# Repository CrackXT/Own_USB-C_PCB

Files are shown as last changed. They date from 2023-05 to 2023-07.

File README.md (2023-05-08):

# USB-C_PCB

PCB files for USB Power Mainboard

# Description

This board enables the installation of a USB-C connection with a voltage and current regulator connected behind it.

Like this... https://www.pololu.com/product/4083

Used to operate your microcontroller board with constant voltage and regulated current via a USB-C power supply. - To limit over-voltage and over-current and prevent damage. 

The board can be produced here (AISLER) with the files (.brd and .sch) or by any other PCB manufacturer. -> https://aisler.net/

# Spec
Vin:  2,8 - 22V<br>
Vout: 5V (typ., min.4,85V, max.5,15V)<br>
Iout: 1A

# Serie

- .pro

# Layout

Top<br>
UBS-C_Top_v4 0

Bottom<br>
UBS-C_Bottom_v4 0

Routing/Dimensions(inch)<br>
USB-C_v4 0

Schematic<br>
Schematic as .pdf at the top of the page.

# License

Open hardware, use it, mod it, whatever you want, feel free...

# Thanks!

Own design and layout.

# Version - Build

v4.0 - 07.05.2023

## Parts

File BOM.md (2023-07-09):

# BOM - List

part list for Use

# USB-C
1x USB-C connector https://www.digikey.de/de/products/detail/gct/USB4125-GF-A-0190/14559038

# regulator
1x S13V10F5 https://eckstein-shop.de/Pololu-5V-1A-Step-Up-Step-Down-Voltage-Regulator-S13V10F5

# connector
1x JST-PH2 (THT - Axial) https://www.reichelt.de/jst-stiftleiste-gerade-1x2-polig-ph-jst-ph2p-st-p185049.html?&trstct=pos_11&nbc=1

# led
1x white 0805 https://www.digikey.de/de/products/detail/everlight-electronics-co-ltd/EAST2012WA1/11200795

# resistor
1x 2200Ohm 0805 https://www.reichelt.de/smd-widerstand-0805-2-2-kohm-125-mw-0-1--spr-0805-2-20k-p123266.html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<br>
2x 5100Ohm 0805 https://www.reichelt.de/smd-widerstand-0805-5-1-kohm-125-mw-0-1--spr-0805-5-10k-p123287.html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<br>

# capacitor
1x 47µF 2220 https://www.digikey.de/de/products/detail/tdk-corporation/C5750X7R1V476M230KC/15930210

# socket strips
1x 1X3 https://www.reichelt.de/buchsenleiste-2-54mm-1x3-gerade-bkl-10120945-p266670.html?&trstct=pol_1&nbc=1

# pin headers
1x 1X36 (1X3) https://www.conrad.de/de/p/fischer-elektronik-stiftleiste-standard-anzahl-reihen-1-polzahl-je-reihe-36-sl-lp-1-082-36-z-1-st-739416.html

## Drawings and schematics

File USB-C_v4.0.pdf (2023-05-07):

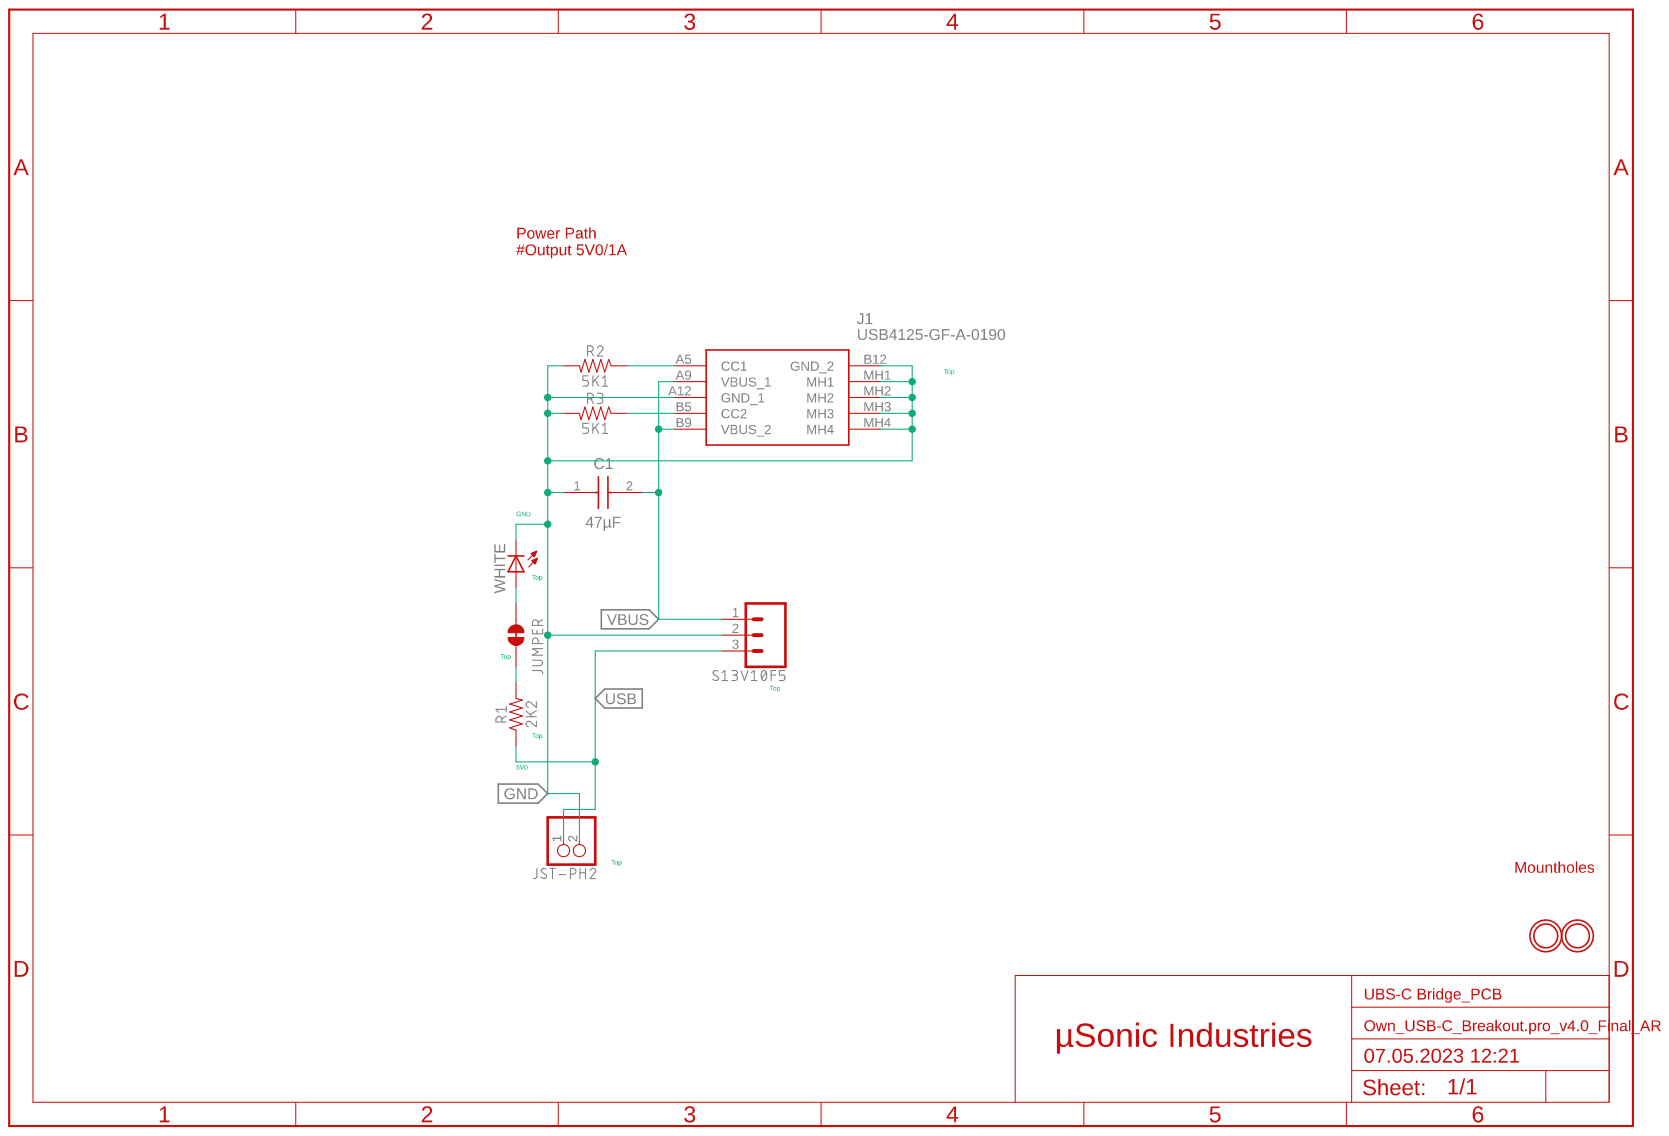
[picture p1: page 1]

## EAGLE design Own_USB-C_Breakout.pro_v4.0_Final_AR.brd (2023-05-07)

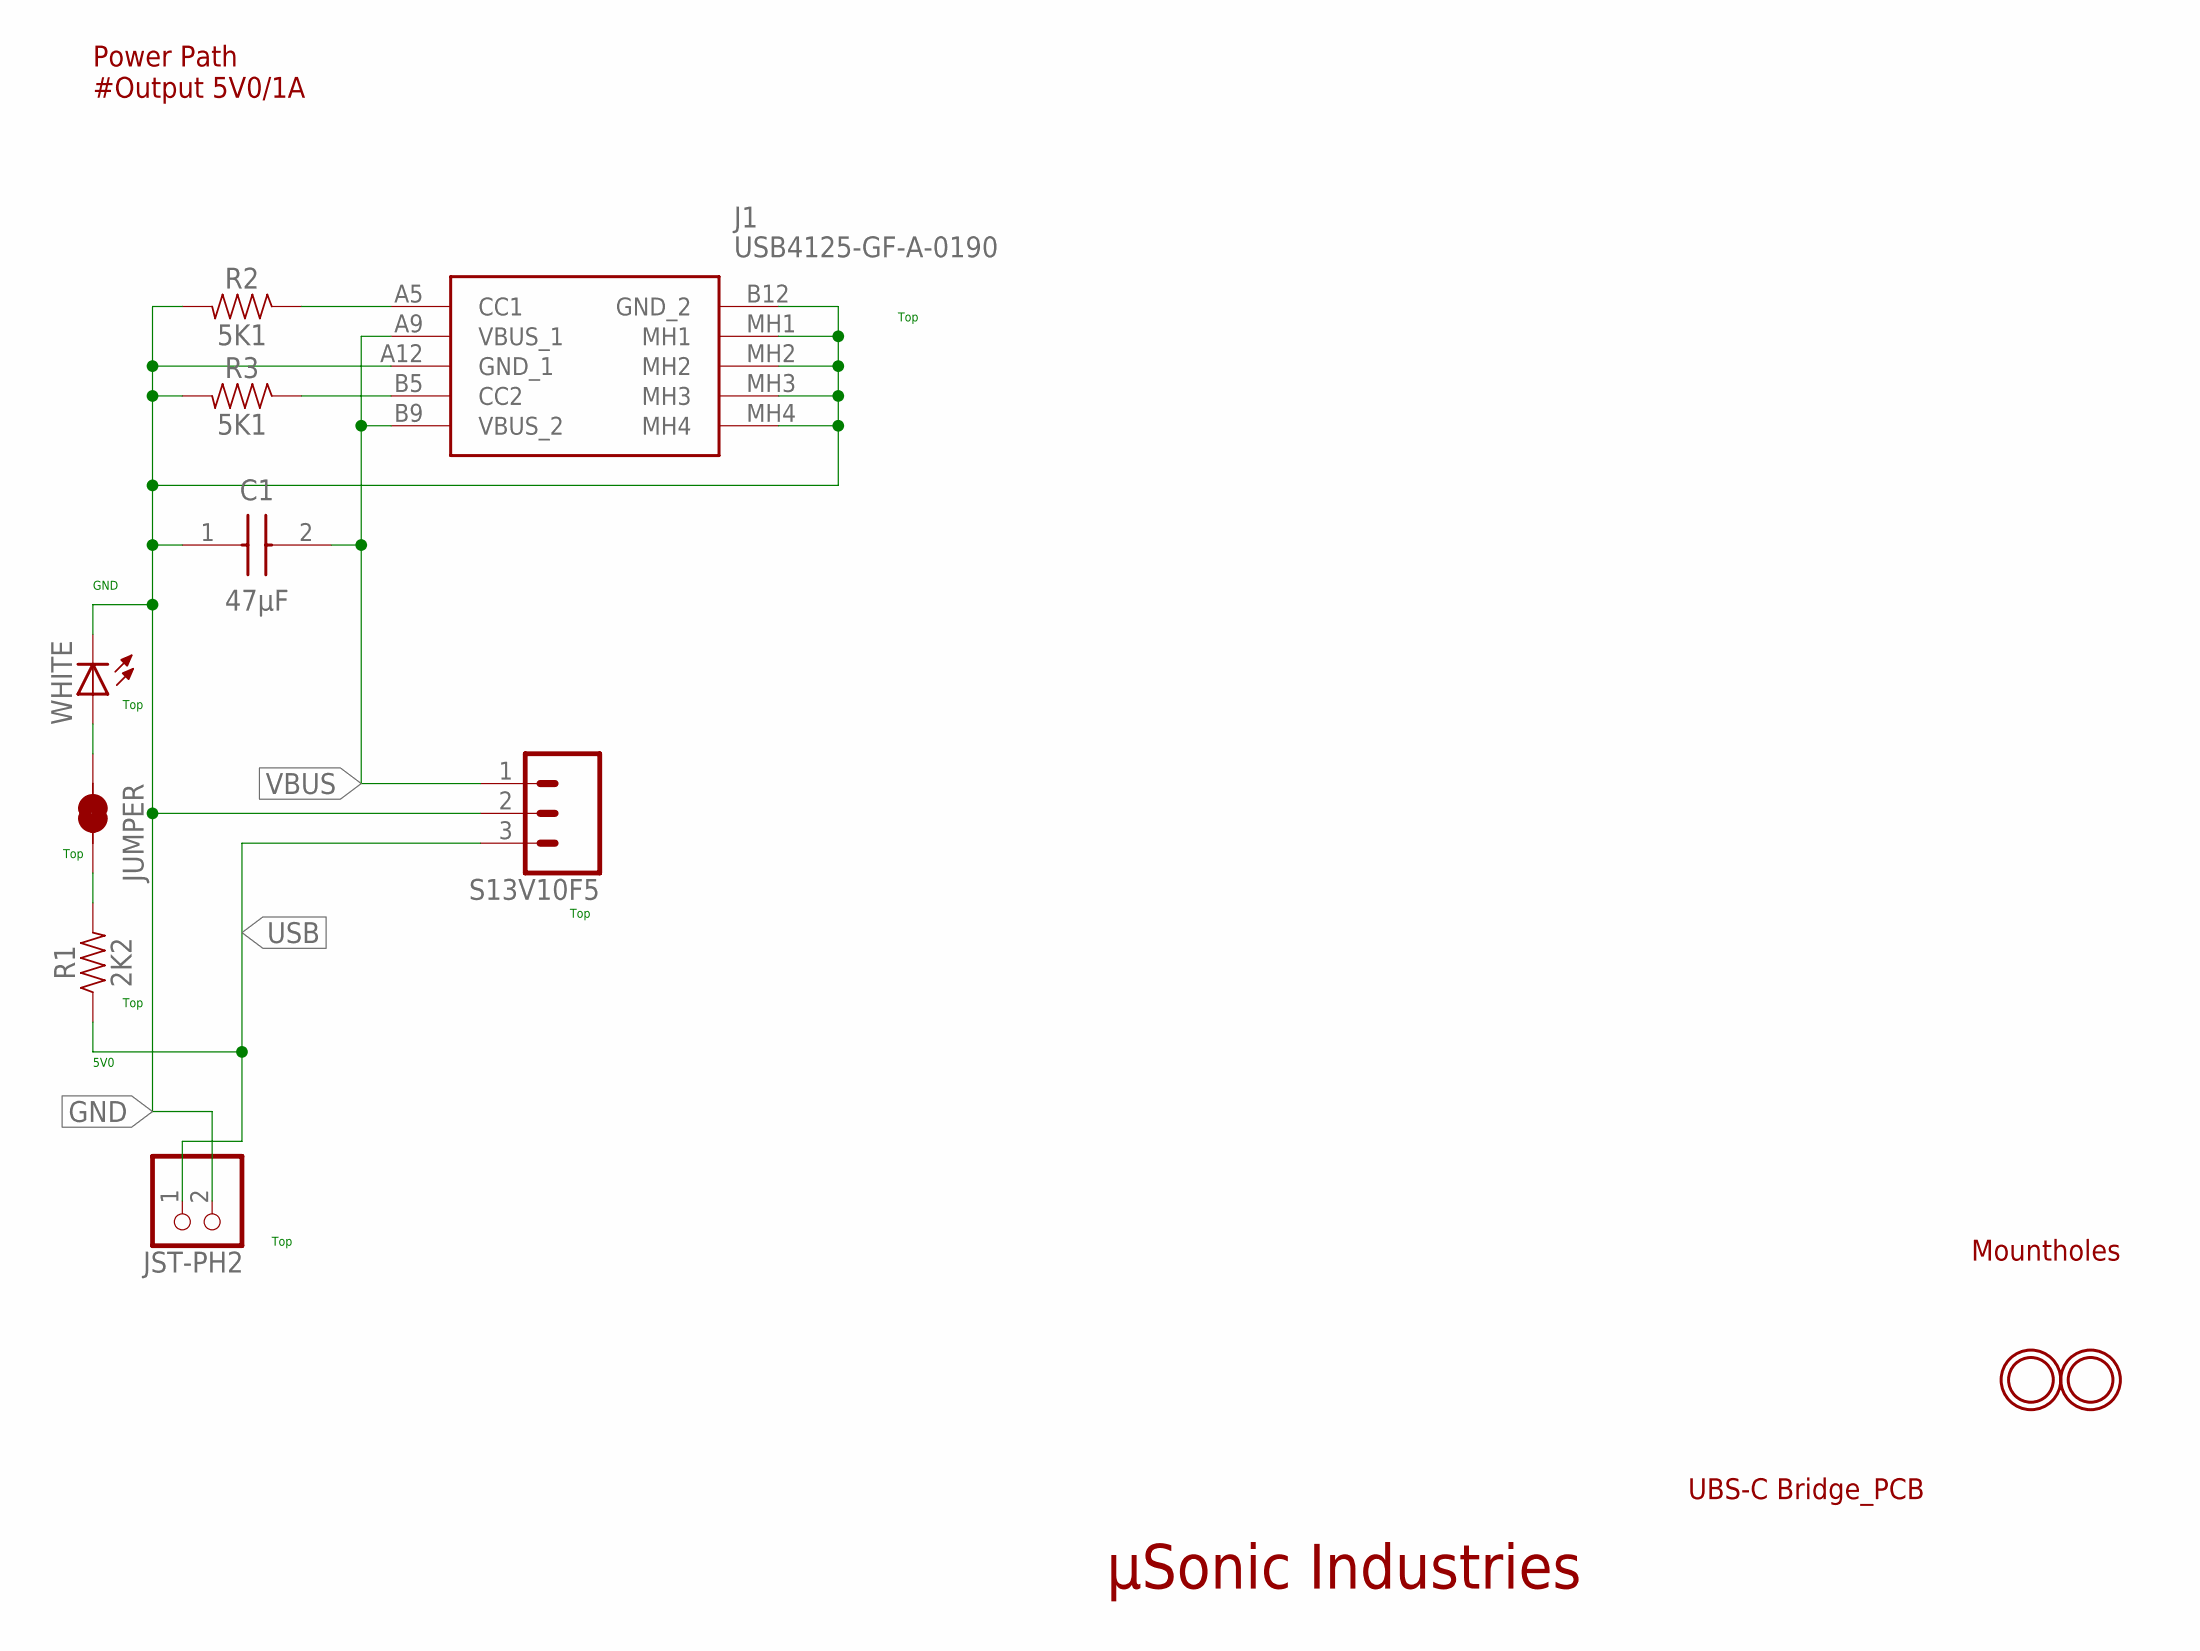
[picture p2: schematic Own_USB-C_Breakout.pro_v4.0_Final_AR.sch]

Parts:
C1: 47µF; CAPC5750X310N
J1: USB4125-GF-A-0190; USB4125GFA0190
JST-PH2: JST_2PINOWN; JST-PH-2-THMOWN
JUMPER: JUMPER-SMT_2_NC_TRACE_SILK; SMT-JUMPER_2_NC_TRACE_SILK
R1: 2K2; 0805
R2, R3: 5K1; 0805
S13V10F5: CONN_031X03_NO_SILK; 1X03_NO_SILK
U$1, U$2: MOUNTINGHOLE2.5; MOUNTINGHOLE_2.5_PLATED
WHITE: LEDCHIPLED_0805; CHIPLED_0805

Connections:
GND: C1.1, J1.A12 (GND_1), J1.B12 (GND_2), J1.MH1, J1.MH2, J1.MH3, J1.MH4, JST-PH2.2 (1), R2.2, R3.2, S13V10F5.2, WHITE.C
JUMPER1: JUMPER.1, WHITE.A
JUMPER2: JUMPER.2, R1.2
unnamed: J1.B5 (CC2), R3.1
unnamed: J1.A5 (CC1), R2.1
USB: JST-PH2.1 (2), R1.1, S13V10F5.3
VBUS: C1.2, J1.A9 (VBUS_1), J1.B9 (VBUS_2), S13V10F5.1

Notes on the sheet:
µSonic Industries
UBS-C Bridge_PCB
Power Path #Output 5V0/1A
Top
Mountholes
GND
5V0

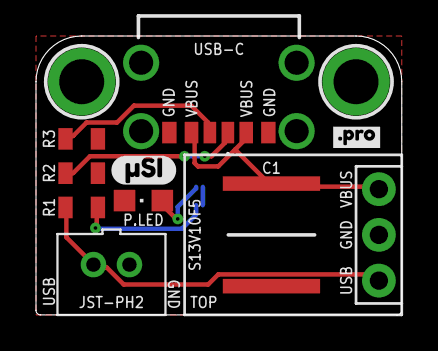
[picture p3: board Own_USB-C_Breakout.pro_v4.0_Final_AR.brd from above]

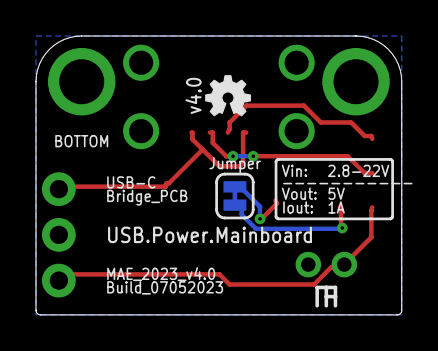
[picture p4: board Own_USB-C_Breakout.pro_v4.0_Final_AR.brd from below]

Board: 2 copper layers, 20.3 x 15.5 mm, 14 parts (2 on the bottom side), 7 nets.

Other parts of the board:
U$4: PRO2
U$6: OSHW-LOGO-MINI
U$7: µSI2

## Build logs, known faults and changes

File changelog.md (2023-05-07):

# Version - Build
v1.0 - 09.10.2021
- First Release

v2.0 - 20.01.2022
- reWork (add LC709203F Slot)
- polarity fix
- INA219 removed
- PCB downsized

v3.0 - 25.06.2022
- reWork (add INA219 and En(able) Pin)
- LC709203F Slot removed
- JST-PH switch from Side to Axial
- LED switch from 0603 to 0805

v3.1 - 26.06.2022
- two resistor solder pads designed for combining the series resistor value
- Font position optimized

v4.0 - 07.05.2023
- reWork (add nativ USB-C port (power only))
- INA219 removed
- Regulator switch from TPS61023 to S13V10F5
- own "Font" Design (Logo, Serie)
- PCB downsized

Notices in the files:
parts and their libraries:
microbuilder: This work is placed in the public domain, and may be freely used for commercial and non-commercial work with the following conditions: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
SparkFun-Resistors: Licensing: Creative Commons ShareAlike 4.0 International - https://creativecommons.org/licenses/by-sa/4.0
